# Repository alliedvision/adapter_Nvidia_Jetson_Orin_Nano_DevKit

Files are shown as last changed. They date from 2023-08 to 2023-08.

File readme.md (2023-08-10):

# Allied Vision Adapter Board CSI-2 for Nvidia Jetson Orin Nano Development Kit

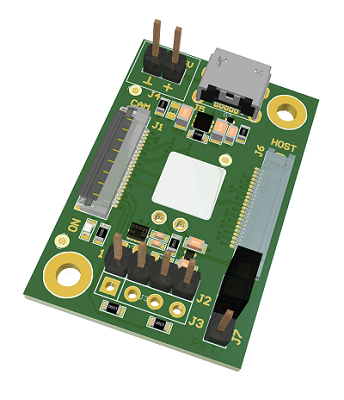
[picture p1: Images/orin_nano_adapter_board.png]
orin_nano_apapter_board


This repository contains open hardware design files for an adapter board supporting the Allied Vision Alvium CSI-2 camera pinout to NVIDIA's Orin Nano Development Kit, created by Allied Vision.
The board allows the user to interface with one Alvium MIPI CSI-2 compatible camera over a Flexible Flat Cable (FFC) connector.

You can also purchase the adapter from [Allied Vision](https://www.alliedvision.com/en/products/accessories/interface-connections/#!?cameraInterfacefilter=10) or from our [distributors](https://www.alliedvision.com/en/avt-locations/avt-distributors/).

## Getting Started

These instructions will get you a copy of the design files to make your own adapter boards for development and testing purposes. 
The board can be produced and assembled using the provided design files. Please take a look at the mechanical layers for more information regarding the PCB stackup recommended for fabrication. 

More information is available on our website:

* [User Guide (PDF)](https://cdn.alliedvision.com/fileadmin/content/documents/products/accessories/embedded/user-guide/Jetson-Orin-Nano_Adapter_User-Guide.pdf)
* [Accessories webpage](https://www.alliedvision.com/en/products/accessories/interface-connections/#!?cameraInterfacefilter=10), 
* [Accessories download webpage](https://www.alliedvision.com/en/support/accessory-documentation/)
* [Alvium CSI-2 download webpage](https://www.alliedvision.com/en/support/technical-documentation/alvium-csi-2-documentation/) 

### Prerequisites

* A running installation of Altium.
* A PCB producer & PCBA manufacturer or some soldering skills.
* Supported SOMs:
	* NVIDIA Jetson Orin Nano Developer Kit 
	* All Raspberry Pi type 22-pin CSI-2 compatible boards (not tested, no driver available)
* One supported MIPI CSI-2 FPC cable
	* Allied Vision product numbers 12316, 12317, 12318, 18947
* One Allied Vision [Alvium CSI-2 camera](https://www.alliedvision.com/en/products/embedded-vision-cameras.html)

### Installing

Open the *CSI2-ORIN-NANO_Rev01.PrjPcb* project file in your Altium environment.

## Built With

* [Altium Designer 22](https://www.altium.com/altium-designer/de)
 
## License

This project is licensed under the MIT License - see the [LICENSE](LICENSE) file for details

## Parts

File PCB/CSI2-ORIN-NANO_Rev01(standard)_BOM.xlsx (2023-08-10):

 | Bill of Materials | CSI2-ORIN-NANO_Rev01
 | Project : | CSI2-ORIN-NANO
 | PCBA : |  | Revision : | 01
 | PCB : |  | Revision : | 01
 | Variant : | standard
 | Schematic : | CSI2-ORIN-NANO_Rev01 | Schematic.pdf
 | Placement : | CSI2-ORIN-NANO_Rev01 | Overlay.pdf
 | Report Date : | 28.07.2023 | 09:33
 | Alternative Parts :
Quantity | Designator | Comment | Footprint | Description | Manufacturer | Manufacturer Part Number | KHK Part Number
1 | C1 | NL | C-0603_1.0 | Capacitor Ceramic SMD/0603/50V/X7R/10% | several | several
2 | C2, C3 | 10u | C-0805_1.4 | Capacitor Ceramic SMD/0805/16V/X5R/10% | several | several | K8340151
1 | C4 | 100n | C-0603_1.0 | Capacitor Ceramic SMD/0603/50V/X7R/10% | several | several | K8340023
2 | C5, C6 | 100n | C-0402_0.55 | Capacitor Ceramic SMD/0402/16V/X7R/10% | several | several | K8340114
2 | C7, C8 | 4u7 | C-0603_1.0 | Capacitor Ceramic SMD/0603/10V/X5R/10% | several | several | 1431
1 | D1 | GREEN | D-0603-LED | Chip LED green 430mcd | Würth | 150060GS75000 | 8172
1 | D2 | ESD9B5.0ST5G | D-SOD923 | DIODE TVS; 400W; 5.8-7.8V; BIDIRECT | ON Semiconductor | ESD9B5.0ST5G | 7250
1 | J1 | CON FFC22_Inverted | J-FH55-22S-0.5SH - Inverted Pins | FFC Connector 0.5mm shielded | Hirose | FH55-22S-0.5SH | 10357
1 | J2 | CON1x4 | CON 1x4 RM2.54 | Header Vertical, 1x4 Pos, Pitch 2.54mm, Contact Length Mating 6.00mm, Contact Length Post 3.00mm, Insulation Height 2.54mm, Gold Plating | several | several | 15343
1 | J3 | NL | CON 1x4 RM2.54 | Header Vertical, 1x4 Pos, Pitch 2.54mm, Contact Length Mating 6.00mm, Contact Length Post 3.00mm, Insulation Height 2.54mm, Gold Plating | several | several
1 | J4 | CON1x2 | CON 1x2 RM2.54 | Header Vertical, 1x2 Pos, Pitch 2.54mm, Contact Length Mating 6.00mm, Contact Length Post 3.00mm, Insulation Height 2.54mm, Gold Plating | several | several | 15337
1 | J5 | USB 2.0 Typ B 90° | J-629105150521 | Micro USB 2.0 Typ B 90° | WE | 629 105 150 521 | 14360
1 | J6 | 54548-2272_Inverted | J-MOLEX-545482272 - INVERTED PINS | CON/W2B/FFC;22-pin;0.5mm;SMT;FEMALE;HORIZONTAL | Molex | 54548-2272 | 20137
1 | J7 | CON1x3 | CON 1x3 RM2.54 | Header Vertical, 1x3 Pos, Pitch 2.54mm, Contact Length Mating 6.00mm, Contact Length Post 3.00mm, Insulation Height 2.54mm, Gold Plating | several | several | 15338
1 | J8 | Jumper | J-JUMPER-2.54 | CON/JUMPER/STC02SYAN; 2-pin; 2.54mm; 3A; FEMALE; VERTICAL; BLACK | several | several | 13444
3 | MRK1, MRK2, MRK3 | Marker Single Layer | PCB_Marker_Pad_top | Position Marker for PCBs
1 | PCB1 |  |  | PCB ML04 | several
1 | R1 | 3k3 | R-0603_0.6 | Standard Resistor SMD/0603/1%/100mW/TK100 | several | several | K8250070
1 | R2 | 0R0 | R-0603_0.6 | Standard Resistor SMD/0603/1%/100mW/TK200 | several | several | K8250041
2 | R3, R6 | NL | R-0603_0.6 | Standard Resistor SMD/0603/1%/100mW/TK200
3 | R4, R7, R9 | 0R0 | R-0603_0.6 | Standard Resistor SMD/0603/1%/100mW/TK100 | several | several | K8250041
1 | R5 | 51k | R-0603_0.6 | Standard Resistor SMD/0603/1%/100mW/TK100 | several | several | K8250156
1 | R8 | 270k | R-0603_0.6 | Standard Resistor SMD/0603/1%/100mW/TK100 | several | several | K8250170
1 | U1 | TPS25200DRVT | IC-DFN06_2.0x2.0x0.8 | IC/PWR/LOADSW;2V5-6V5;2A5;0R099/6-WDFN/2x2x0.8mm | Texas Instruments | TPS25200DRVT | 14277
1 | U2 | NCP103AMX180TCG | IC-XDFN4_1.0x1.0x0.6 | IC/PWR/LDO;2V0-5V5;1V8;0A150/uDFN4/1x1x0.6mm | ON Semi | NCP103AMX180TCG | 14922
1 | U3 | NTB0104GU12,115 | IC-XQFN12_1.7x2x0.5 | IC/LOGIC/Levelshifter;Auto-Dir;Bidirectional;Push-Pull;-40-+125°C/ | NXP | NTB0104GU12,115 | 14383

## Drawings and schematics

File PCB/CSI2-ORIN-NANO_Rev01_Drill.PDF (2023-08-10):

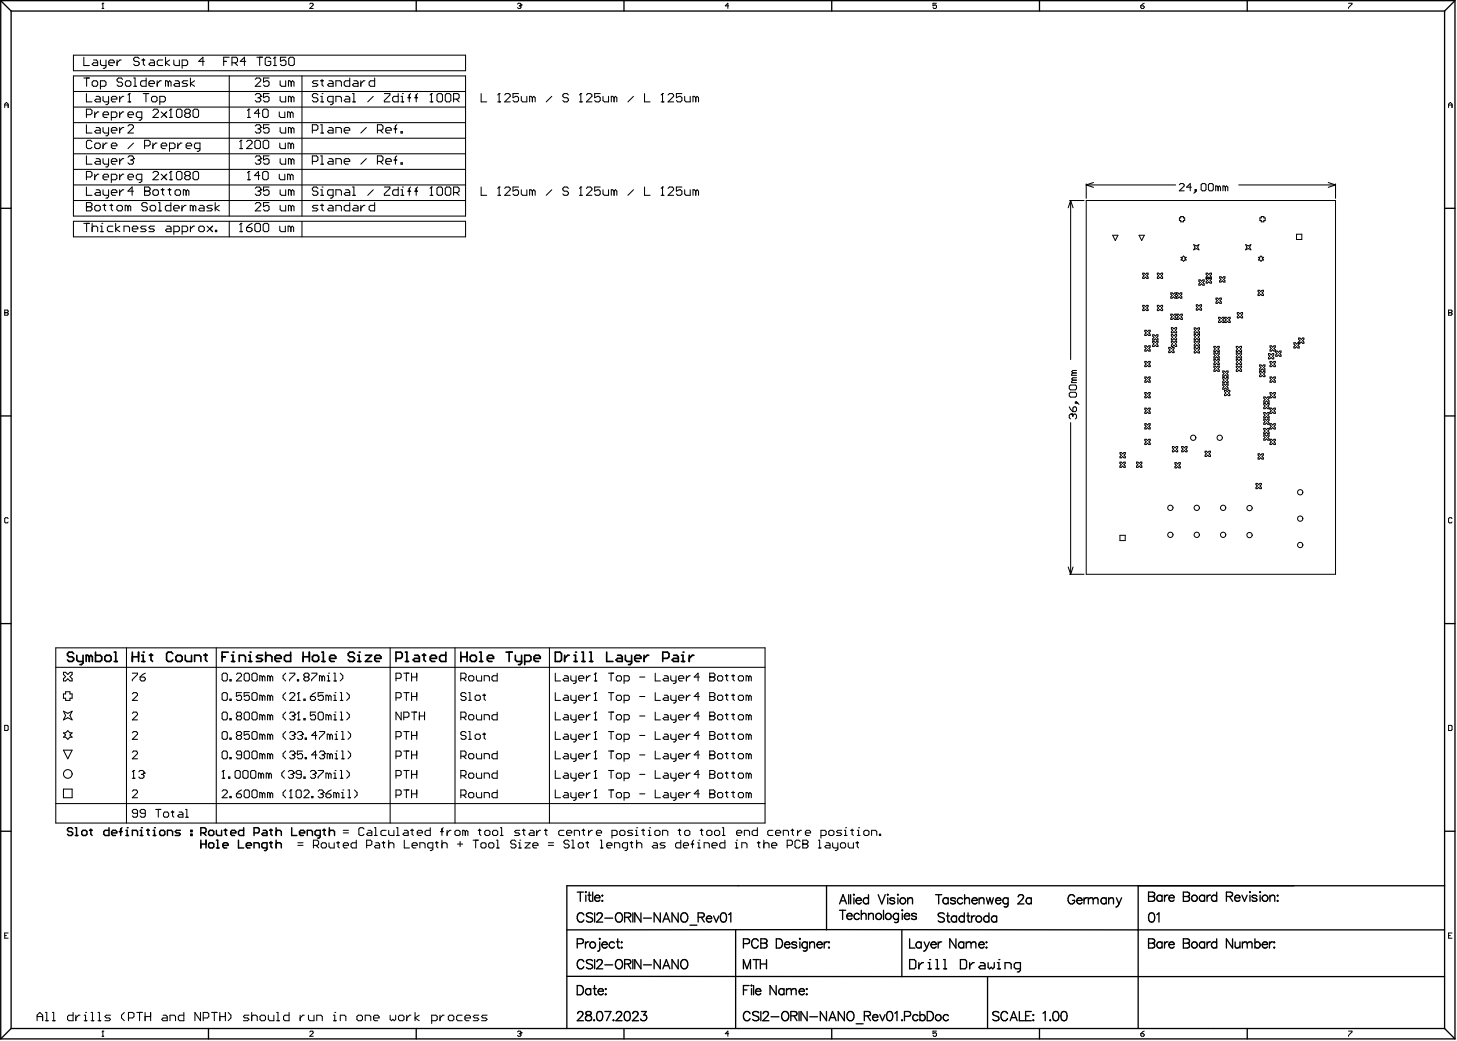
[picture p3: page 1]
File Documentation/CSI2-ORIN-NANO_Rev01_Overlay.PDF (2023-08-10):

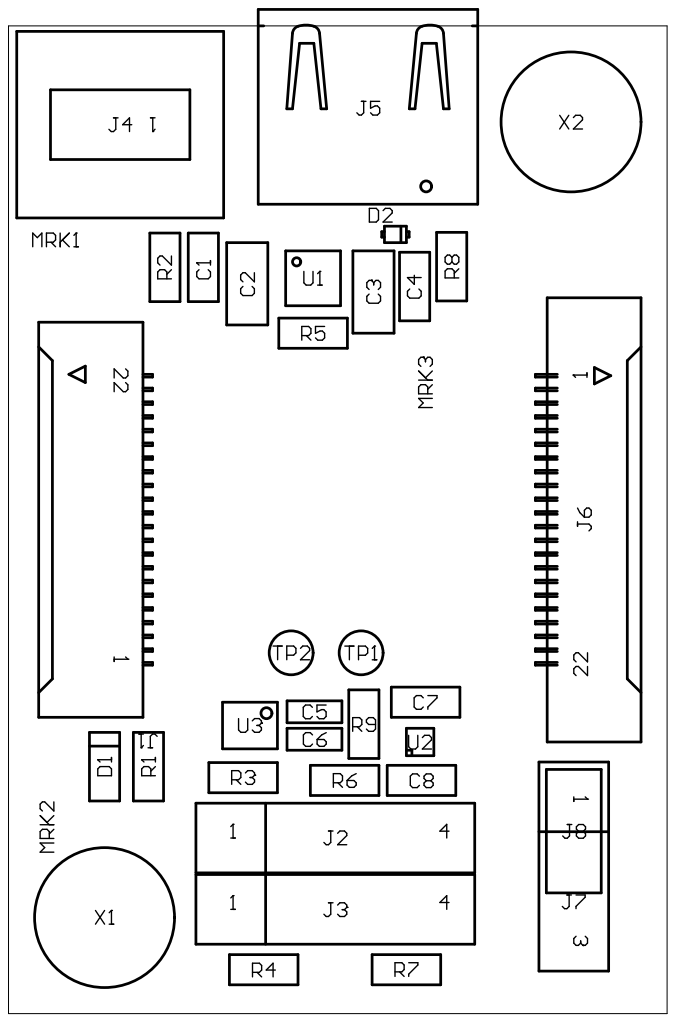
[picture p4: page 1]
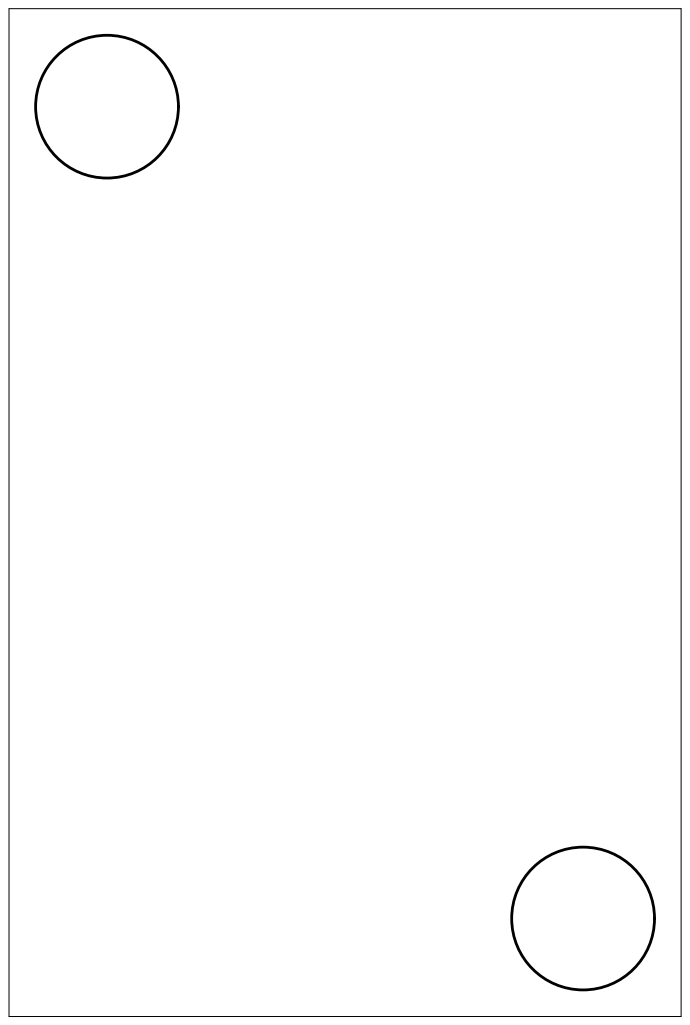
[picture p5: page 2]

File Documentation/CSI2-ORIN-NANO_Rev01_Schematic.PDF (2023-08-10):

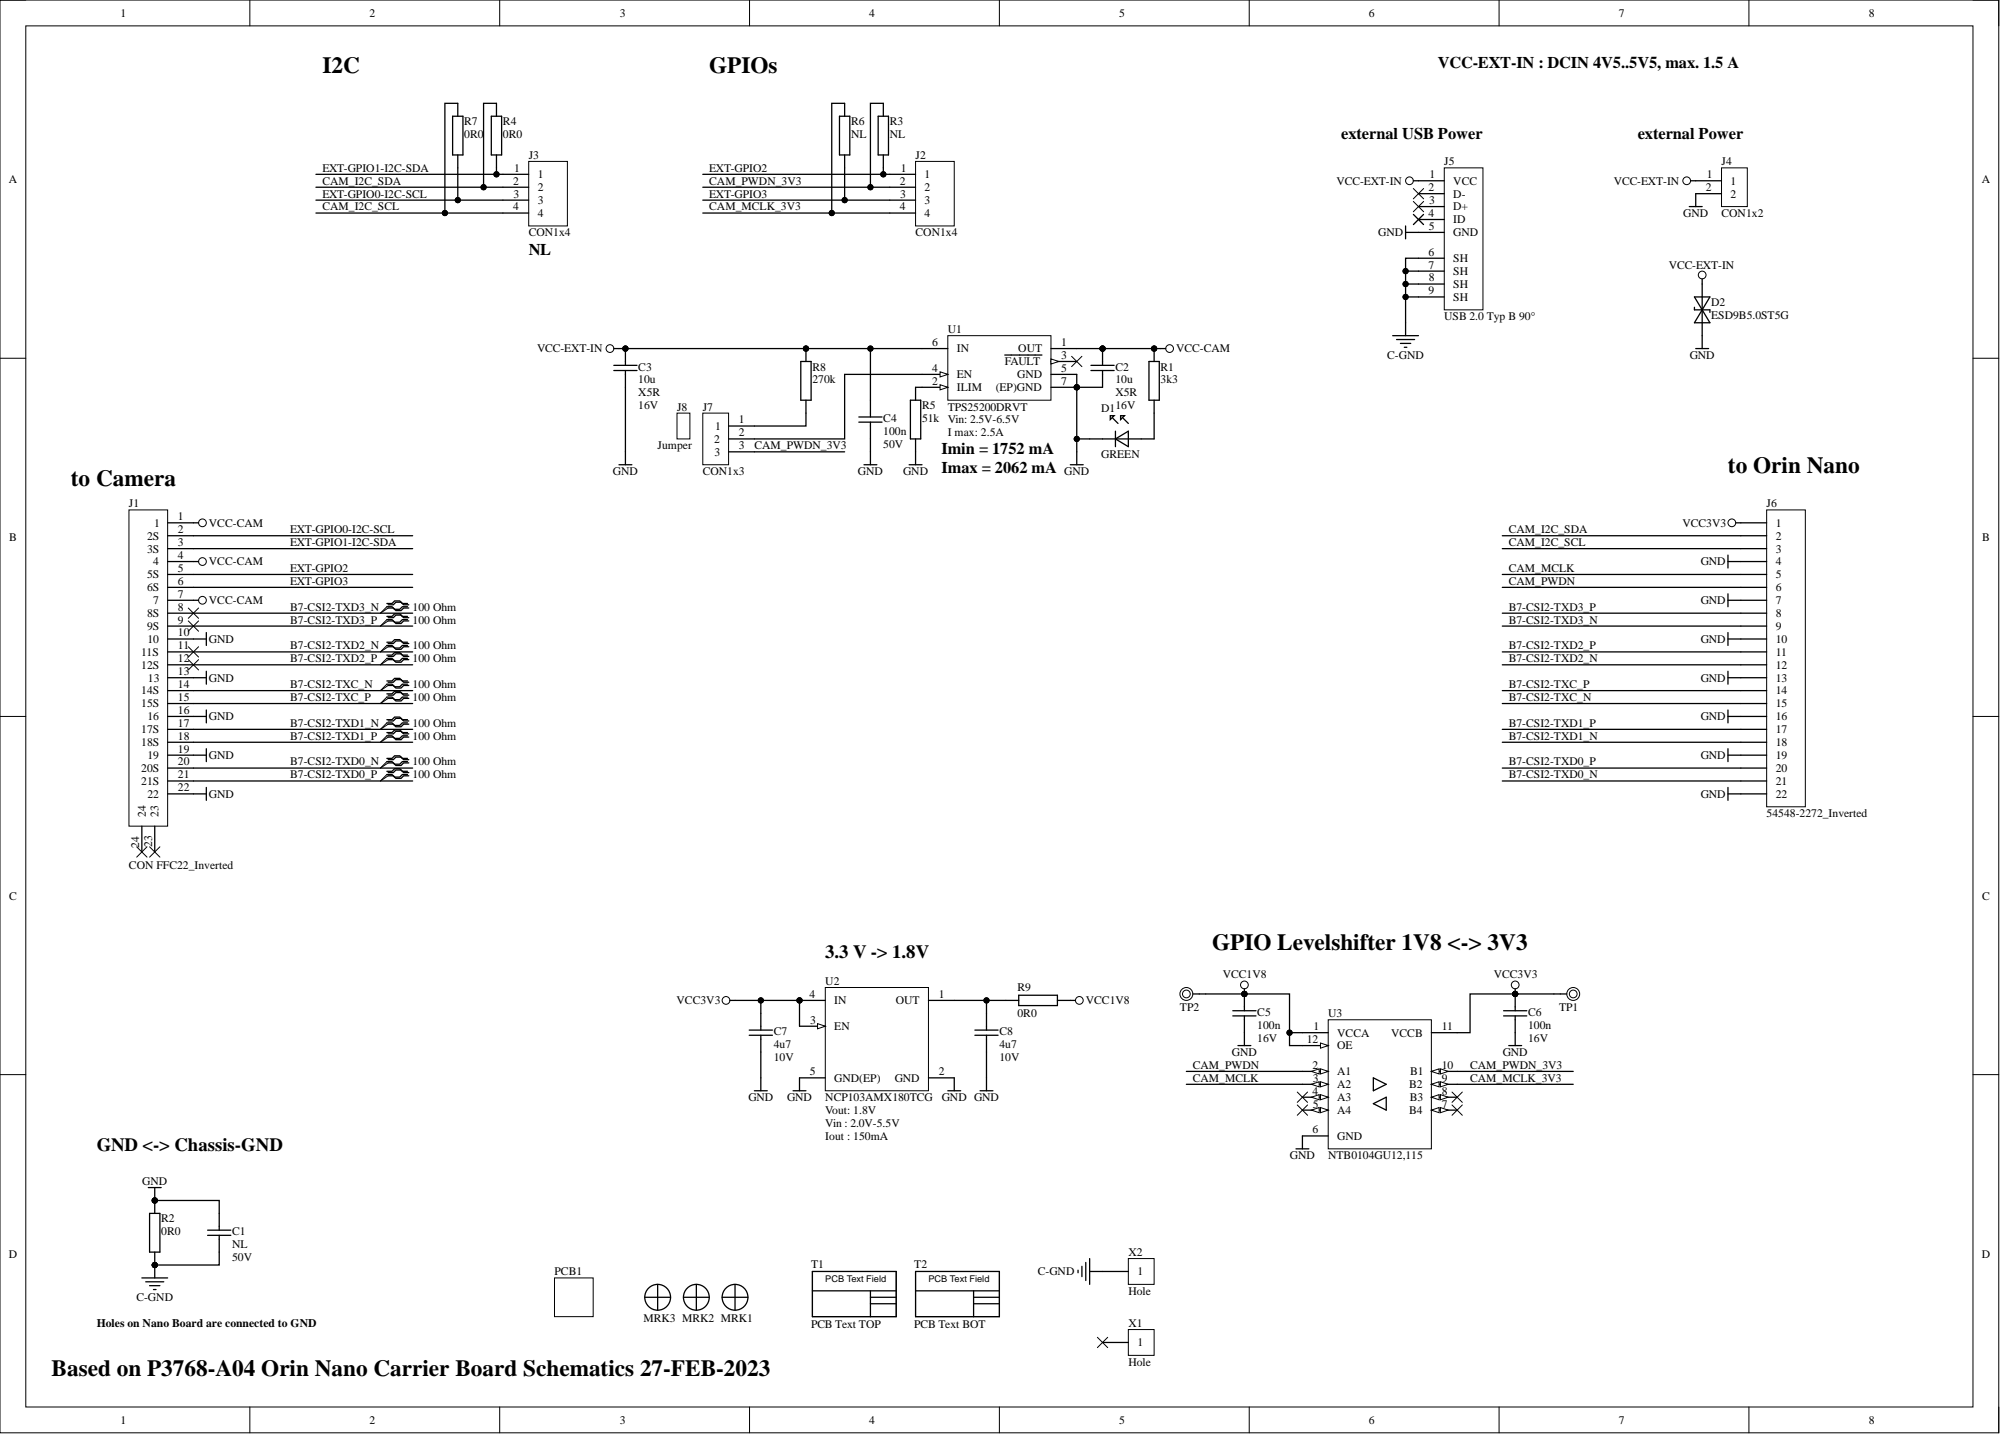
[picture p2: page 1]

VCC-EXT-IN : DCIN 4V5..5V5, max. 1.5 A

Holes on Nano Board are connected to GND

Based on P3768-A04 Orin Nano Carrier Board Schematics 27-FEB-2023
